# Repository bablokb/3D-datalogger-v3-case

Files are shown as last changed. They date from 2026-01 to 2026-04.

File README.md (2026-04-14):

A case for the Pico-Datalogger v3
=================================

This project provides the 3D-design-files (OpenSCAD) for a case
for the Pico Datalogger (see https://github.com/bablokb/pcb-datalogger-v3).

Case with battery lid:

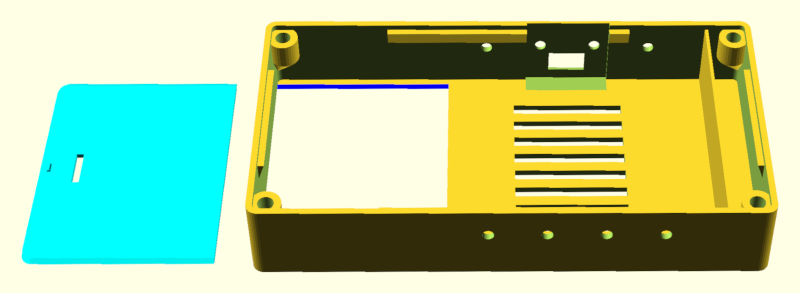
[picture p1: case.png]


Assembled case with panel:

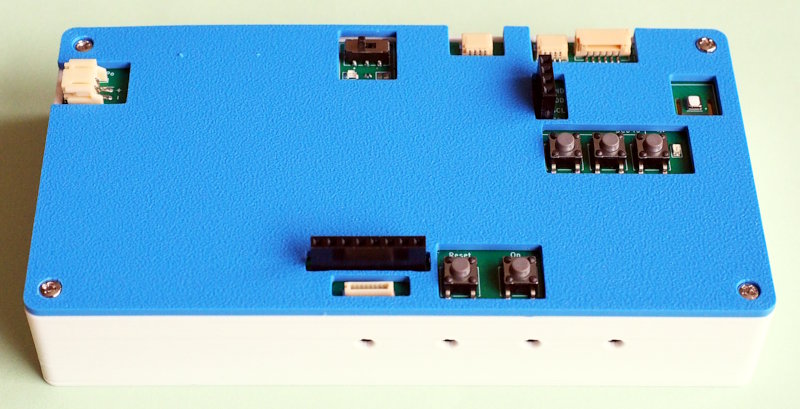
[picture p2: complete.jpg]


With additional display, using this [display
adapter](https://github.com/bablokb/pcb-datalogger-display-adapter-v2):

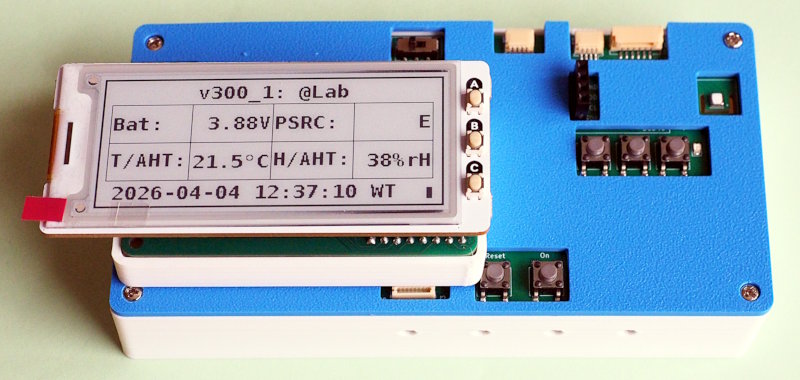
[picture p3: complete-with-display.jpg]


License
-------

[![CC BY-SA 4.0][cc-by-sa-shield]][cc-by-sa]

This work is licensed under a
[Creative Commons Attribution-ShareAlike 4.0 International
License][cc-by-sa].

[][cc-by-sa]

[cc-by-sa]: http://creativecommons.org/licenses/by-sa/4.0/
[cc-by-sa-image]: https://licensebuttons.net/l/by-sa/4.0/88x31.png
[cc-by-sa-shield]:
https://img.shields.io/badge/License-CC%20BY--SA%204.0-lightgrey.svg

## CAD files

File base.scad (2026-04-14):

// ---------------------------------------------------------------------------
// 3D-Model (OpenSCAD): Base for Datalogger-v3 PCB. 
//
// Author: Bernhard Bablok
// License: GPL3
//
// https://github.com/bablokb/pcb-pico-datalogger
// ---------------------------------------------------------------------------

include <BOSL2/std.scad>
include <shared.scad>
include <sliding_lid.scad>
include <threaded_case.scad>

// ethernet (EVB-Pico)
HAVE_ETH = false;
X_ETH = 22;
H_ETH = BT + 2;

Z_CASE = HAVE_ETH ? 30:20;
X_LID  = 50;

// USB-cutout
X_USB = 10;                  // x-size cutout
O_USB = 16.46;               // offset from y==0
Z_USB =  6;                  // z-size cutout
H_USB = BT+Z_CASE-11-Z_USB;  // height of cutout (offset from z==0)
X_PICO_SOCKETS = 9*2.54;     // Pico is 21mm, this is 22.86

// AHT20 wall
O_AHT20 = 10.2;              // offset from right side

// ventilation
X_VENT_B = 30;
Y_VENT_B =  3;
N_VENT_B =  8;
D_VENT_S =  3;
N_VENT_S =  4;

// --- base composite object   ------------------------------------------------

module base(lid=true) {
  difference() {
    union() {
      // case and all supports
      case_threaded(X_PCB, Y_PCB, z_pcb=Z_PCB,
                     z_case=Z_CASE, z_base=BT, wall=W_PANEL, rounding=R_PANEL
                   );
      // AHT20 wall
      if (!HAVE_ETH) {
        xmove(X_PCB/2-O_AHT20)
          cuboid([W2,Y_PANEL,Z_CASE-Z_PCB+BT], anchor=BOTTOM+CENTER);
      }
    }
    // ventilation bottom
    zmove(-FUZZ) xmove(O_USB)
      ycopies(2*Y_VENT_B, n=N_VENT_B)
        cuboid([X_VENT_B,Y_VENT_B,BT+2*FUZZ], anchor=BOTTOM+CENTER);
    // ventilation sides
    zmove(H_USB+Z_USB+D_VENT_S) xmove(O_USB)
      xcopies(1.5*X_USB,n=N_VENT_S)
        ycyl(l=2*Y_PANEL,d=D_VENT_S);
    // USB-cutout
    move([O_USB,Y_PANEL/2,H_USB])
      cuboid([X_USB,6*W_PANEL,Z_USB], anchor=BOTTOM+CENTER);
    // cutout for Pico sockets
    move([O_USB,Y_PANEL/2-2*W_PANEL,BT-FUZZ])
      cuboid([X_PICO_SOCKETS,3*W_PANEL,Z_CASE+2*FUZZ], anchor=BOTTOM+CENTER);
    // ethernet
    if (HAVE_ETH) {
      move([O_USB,-Y_PANEL/2,H_ETH])
        cuboid([X_ETH,6*W_PANEL,Z_CASE], anchor=BOTTOM+CENTER);
    }
    // battery lid
    if (lid) {
      zmove(-FUZZ) xmove(-X_PANEL/2+X_LID/2-FUZZ)
        color("blue")
          lid(X_LID,Y_PANEL-2*W_PANEL, w=W_PANEL,
	                               r=[0,0,0,0], reverse=false, mask=true);
    }
  }
}

// --- final objects   --------------------------------------------------------

// test-print part of base to check lid
//intersection() {
//  base();
//    xmove(-X_PANEL/2+X_LID/2)
//      cuboid([X_LID+10,Y_PANEL+10,5], anchor=BOTTOM+CENTER);
//}

// base and lid
lid = true;
xdistribute(10, sizes=[X_LID,X_PANEL]) {
  if (lid) {
    //xmove(30)
    //xmove(-X_PANEL/2+X_LID/2) zmove(GAP)
       color("aqua") lid(X_LID,Y_PANEL-2*W_PANEL, w=W_PANEL, r=[0,3,3,0],
                         reverse=false, mask=false);
  }
  base(lid);
}

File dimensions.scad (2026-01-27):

// ---------------------------------------------------------------------------
// 3D-Model (OpenSCAD): generic dimensions.
//
// Author: Bernhard Bablok
// License: GPL3
//
// https://github.com/bablokb/pcb-pico-datalogger
// ---------------------------------------------------------------------------

$fa = 1;
$fs = 0.4;
$fn= $preview ? 32 : 128;

FUZZ = 0.01;
W2 = 0.86;                 // 2 walls
W4 = 1.67;                 // 4 walls
GAP = 0.2;                 // GAP pcb to case

BT = 1.8;                  // base thickness

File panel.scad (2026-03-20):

// ---------------------------------------------------------------------------
// 3D-Model (OpenSCAD): Panel for Datalogger-v3 PCB. 
//
// Author: Bernhard Bablok
// License: GPL3
//
// https://github.com/bablokb/pcb-pico-datalogger
// ---------------------------------------------------------------------------

include <BOSL2/std.scad>
include <shared.scad>

ANCHOR = BOTTOM+LEFT+BACK;

// --- generic module to a cover for a PCB   ---------------------------------

module cover(x, y, w, z=Z_PANEL,
             d_screw=2.5, o_screw=3, h_screw=1.4, d2_screw=4.28,
             r=3, edges="Z", screws=true) {
  difference() {
    // solid space
    cuboid([x,y,z], rounding=r, edges=edges, anchor=ANCHOR);
    // minus screw-holes
    if (screws) {
      move([w+o_screw,-w-o_screw,-FUZZ]) {
          cylinder(d=d_screw, h=Z_PANEL,anchor=BOTTOM+CENTER);
          zmove(Z_PANEL-h_screw+FUZZ) 
            cylinder(d=d2_screw, h=Z_PANEL,anchor=BOTTOM+CENTER);
      }
      move([x-w-o_screw,-w-o_screw,-FUZZ]) { 
        cylinder(d=d_screw, h=Z_PANEL+2*FUZZ,anchor=BOTTOM+CENTER);
        zmove(Z_PANEL-h_screw+FUZZ) 
          cylinder(d=d2_screw, h=Z_PANEL,anchor=BOTTOM+CENTER);
      }
      move([w+o_screw,-y+w+o_screw,-FUZZ]) {
        cylinder(d=d_screw, h=Z_PANEL,anchor=BOTTOM+CENTER);
        zmove(Z_PANEL-h_screw+FUZZ) 
          cylinder(d=d2_screw, h=Z_PANEL,anchor=BOTTOM+CENTER);
      }
      move([x-w-o_screw,-y+w+o_screw,-FUZZ]) { 
        cylinder(d=d_screw, h=Z_PANEL,anchor=BOTTOM+CENTER);
        zmove(Z_PANEL-h_screw+FUZZ) 
          cylinder(d=d2_screw, h=Z_PANEL,anchor=BOTTOM+CENTER);
      }
    }
  }
}

// --- final object   -------------------------------------------------------

module panel() {
  Z_PANEL_FUZZ = Z_PANEL+2*FUZZ;
  // cover minus all cutouts
  difference() {
    // create a slightly larger cover and move it to simplify coordinates 
    move([-W_PANEL,W_PANEL,0])
      cover(X_PANEL, Y_PANEL, W_PANEL);
    // JST-PH2 (remove for 300_3, 300_5)
    move([-W_PANEL-FUZZ,-8,-FUZZ])
      cuboid([13+W_PANEL+FUZZ,11,Z_PANEL_FUZZ], anchor=ANCHOR);
    // pins battery-holder (remove for 300_3, 300_5)
    move([22,-5.5,-FUZZ]) cylinder(d=2.5, h=H_PINS+FUZZ,anchor=ANCHOR);
    move([37,-5.5,-FUZZ]) cylinder(d=2.5, h=H_PINS+FUZZ,anchor=ANCHOR);
    // power-switch (remove for 300_3, 300_5)
    move([54,0,-FUZZ]) cuboid([11.5,13,Z_PANEL_FUZZ], anchor=ANCHOR);
    // pins Pico-W
    move([71,0,-FUZZ]) cuboid([3,52,H_PINS+FUZZ], anchor=ANCHOR);
    move([88.7,0,-FUZZ]) cuboid([3,52,H_PINS+FUZZ], anchor=ANCHOR);
    // JST-SH4 (i2c0) (remove vor 300_5)
    move([76,+W_PANEL+FUZZ,-FUZZ])
      cuboid([11,6.5+W_PANEL+FUZZ,Z_PANEL_FUZZ], anchor=ANCHOR);
    // JST-SH4 (i2c1) + GH6 (SEN66) (xsize+12: UART5V)  (remove for 300_5)
    move([92.3,+W_PANEL+FUZZ,-FUZZ])
      cuboid([21,8+W_PANEL+FUZZ,Z_PANEL_FUZZ], anchor=ANCHOR); // I2C1+GH6
      //cuboid([11,8+W_PANEL+FUZZ,Z_PANEL_FUZZ], anchor=ANCHOR);   // only I2C1
    // SCD40/OLED
    move([91.88,-10.95,-FUZZ])
       cuboid([6.42,12,Z_PANEL_FUZZ], anchor=ANCHOR);
    // AHT20  (remove for 300_3, 300_5)
    move([119,-11,-FUZZ])
       cuboid([9.1,10.5,Z_PANEL_FUZZ], anchor=ANCHOR);
    // Buttons A-C
    move([93,-24,-FUZZ]) cuboid([28,12,Z_PANEL_FUZZ], anchor=ANCHOR);
    // LoRa-antenna
    move([112,-57.5,-FUZZ]) cylinder(d=4, h=H_PINS+FUZZ,anchor=ANCHOR);
    // Buttons Reset+ON
    move([72,-52.5,-FUZZ]) cuboid([19,12,Z_PANEL_FUZZ], anchor=ANCHOR);
    // Buttons Reset only (for 300_3, 300_5)
    //move([72,-52.5,-FUZZ]) cuboid([9.5,12,Z_PANEL_FUZZ], anchor=ANCHOR);
    // Display-connector SURS (remove for 300_3, 300_5)
    move([53,-59.5,-FUZZ]) cuboid([14,4.5,Z_PANEL_FUZZ], anchor=ANCHOR);
    // Display-connector THT
    move([48.30,-54.145,-FUZZ]) cuboid([22.5,4.5,Z_PANEL_FUZZ], anchor=ANCHOR);
  }
}

// final object, rotated for printing
xrot(180)
  panel();

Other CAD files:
ruthex.scad
fase.scad
shared.scad
sliding_lid.scad
threaded_case.scad

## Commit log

2026-02-17 added comments
    [sliding_lid.scad]
2026-02-17 make lid symmetric
    [sliding_lid.scad]
2026-02-17 add module 'guides()'
    [sliding_lid.scad]
2026-02-17 rename 'hull' to 'mask'; make lid small than mask
    [base.scad, sliding_lid.scad]
2026-03-10 fine-tune dimensions of lid
    [sliding_lid.scad]
2026-03-11 comment out test-prints and activate productive prints
    [base.scad]
2026-03-13 add cutout for THT display connector
    [panel.scad]
2026-03-17 add cutout for SCD40/OLED connector
    [panel.scad]
2026-03-18 rotate panel for printing
    [panel.scad]
2026-03-19 fix location of display-THT cutout; remove LoRa-antenna cutout
    [panel.scad]
2026-03-20 add LoRa-antenna cutout again in pin-height
    [panel.scad]
2026-03-20 mark optional cutouts
    [panel.scad]
2026-03-20 support printing without lid
    [base.scad]
2026-03-25 support datalogger with EVB-Pico attached
    [base.scad]
2026-04-10 refactored code to threaded_case.scad
    [base.scad, threaded_case.scad]
2026-04-10 add GAP to nut-size
    [ruthex.scad]
2026-04-14 fixed errors introduced by refactoring
    [base.scad, threaded_case.scad]
